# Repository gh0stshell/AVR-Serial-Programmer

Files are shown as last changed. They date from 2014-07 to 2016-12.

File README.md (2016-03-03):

AVR Serial Programmer
---------------------

This project is a small programmer for AVR microcontrollers using an RS232
serial connection. The circuit has a feature that allows the firmware to be
loaded to the target microcontroller, and the serial line to be passed through
to the target without manual intervention. A jumper setting allows for the
programmer firmware to be updated. The microcontroller used in the programmer
hardware is now the ATTiny4313. The original AT90S2313 is obsolete and the
ATTiny2313 is now too limited.

The firmware manages the programming of an expandable range of AVR
microcontrollers, FLASH, EEPROM and fuse bits, using the SPI port of the target
with the reset pin asserted. Versions of firmware are provided for the
ATTiny2313 and ATTiny4313. The former is deprecated. The latter is needed to
handle the increasing number of AVR target types.

A Linux GUI is provided. This reads the AVR fuse bits and signature bits and
adapts the GUI configuration to the detected microcontroller type. The GUI may
be used directly with a bootloader following the AVR109 command interface.

* Connect the 2-pin 5V DC power, noting the polarity is respected.
* Connect a 4-wire serial cable to the PC either directly if the PC has a serial
port, or via a serial-USB adapter. The default serial port is /dev/ttyUSB0
appropriate for the adapter. The -P command line switch allows another port to
be defined, such as /dev/ttyS0 for the PC's serial port.
* Connect the 6-pin programming cable to the target.

The GUI when invoked should show the target AVR processor type plus a number of
additional details. If the serial port is incorrect the GUI will try out a
number of baud rates and close.

Take care when changing the lock/fuse bits as this can brick the processor if
done incorrectly.

More information is provided at [Jiggerjuice](http://www.jiggerjuice.info/electronics/projects/serialprogrammer/firmware-bootloader.html).

(c) K. Sarkies 19/07/2014

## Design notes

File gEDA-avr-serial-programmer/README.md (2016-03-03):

AVR Serial Programmer PCB
-------------------------

This provides the schematic and PCB layout using gEDA and the associated pcb
tools. The final PCB is bundled with some SMPS circuits.

Tested OK.

More information is provided at [Jiggerjuice](http://www.jiggerjuice.info/electronics/projects/serialprogrammer/firmware-bootloader.html)

(c) K. Sarkies 8/11/2014

TODO
The 10 pin header will only just allow a shrouded header for a tight fit. The
board needs to be rearranged to make more room.

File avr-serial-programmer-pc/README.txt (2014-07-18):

AVR Serial Programmer GUI
=========================

Copyright 2007 Ken W. Sarkies

Target:    Linux
Author:    Ken Sarkies
Date:      28/4/2012
Licence:   GPL 2
gcc:       4.6.1
QT         4.7.4
Tested:    ATMega88, ATMega48, ATMega168, ATMega16, ATMega32, ATMEga8535,
ATTiny2313, ATTiny461, ATTiny24, ATTiny44, ATTiny84, ATTiny4313.

Depends QT4 v4.7.4, qextserialport v1.2beta1

The Serial Programmer GUI is intended for use with an AVRPROG compatible Serial
Programmer or with AVR microcontrollers that have an AVR109 compatible
bootloader installed. Normally a bootloader would need to be obtained, compiled
and programmed into the microcontroller using a suitable programming tool. Once
this has been done, the microcontroller can be contacted over an RS232 serial
line to program an application into the device. The programmer begins by opening
the PC serial port ttyUSB0 for use with a Prolific compatible USB-serial
converter. This can be changed as necessary (for example to ttyS0 if you are
using a serial port) by editing the avrserialprogmain.cpp file.

The programmer synchronizes with the device using no parity, 1 stop bit and 8
bit data. A character 0xDD is sent and the character received back from the
device is checked for either a 0xDD or a "?". The latter indicates that the
bootloader may have been found. The 0xDD character relates to the packet
protocol used in the Acquisition project. If this is received, then a packet is
sent to instruct the device to jump into the bootloader. This can be removed if
the application protocol is not needed, but that is probably not necessary.
Needless to say if the bootloader is not present the device will probably just
reset itself. If neither character is received, the baud rate is cyclically
changed through a set of standard rates for a couple of cycles before giving up.

When the program has synchronized with the device, it presents an information
window. An Intel hex file can be opened and it will be immediately read and
loaded to the application area of the FLASH memory (a bootloader is never
overwritten by this; it can only be changed through the parallel or SPI
programming method).

The default baud rate to start with is 38400 baud. If this does not match that
of the device, then the program will cycle through standard baud rates between
2400 and 57600 baud until it finds the correct one. This process can be sped up
by changing the default baud rate to match that of the programmer or bootloader.
Care must be taken with choice of baud rate as the higher rates are not
necessarily produced accurately by an MCU. In addition there are time delays,
built into the code to adapt the program to the communication response time,
that may prevent the application from working reliably. The GUI was tested
successfully with 38400 baud and 8MHz MCUs. Repetitive programming failures,
particularly in block mode programming and verification, could be due to use
with an MCU of lower frequency that takes longer to process a programming
command.

The program allows for turning off block mode, and also allows verification
without programming and vice-versa. Autoaddress currently does nothing so it is
disabled. A debug switch allows masses of information to be dumped to standard
input. Dialogue boxes for programming lock and fuse bits are provided for a
small range of devices.

The application is presented as a QT dialogue box rather than a main window. It
is done this way to allow direct integration into other applications without
recoding. When the application is closed with the Close button it automatically
instructs the bootloader to jump into the program that was just loaded.

For the AVR microcontrollers, control of program loading to the FLASH memory,
and manipulating of the fuse and lock bits for configuring certain features of
the microcontroller, can be simply done through a PC parallel port programmer
(see the cdk4avr tools howto and references). Many of the AVRs provide a small
section of FLASH memory with capabilities that allow it to modify its own FLASH
memory. This is sometimes referred to as the bootblock. It normally resides in
the top of FLASH memory and can be set, through fuse bits, to different sizes,
typically 256 bytes to 4K bytes. The microcontroller can also be configured
through a fuse bit so that after a reset, a jump directly to the bootloader
section can be forced, rather than the usual jump to address 0.

For microcontrollers that have a UART, programming can be done through a PC
serial port using the bootloader. This makes programming even simpler,
particularly for PCs and laptops that do not have a parallel port. For those
without a serial port, a commercially available USB to serial adaptor can be
used.

Some tools developed for AVR programming are presented here. Similar tools are
available in both open source and commercial versions, including bootloaders, PC
programming control applications and hardware programmers. The tools described
here were constructed to add some useful features.

    *      AVR109 Bootloader adaptation
    *      Serial Programmer GUI software
    *	   Installation
    *      Serial to SPI Programmer Hardware
    * 	   Other Open Source Programmers

AVR Bootloader

Atmel's application note AVR109 describes a bootloader that uses the UART to
communicate FLASH programming instructions. They also provide some sample code
in C that allows the programming of FLASH, EEPROM, and lock bits. Note that the
AVR109 bootloader does not support the programming of fuses which for safety
cannot be changed by the bootloader. The communication protocol used is
compatible with the AVRPROG programming software. After loading this into the
bootloader section, the device can be configured so that on reset the program
counter starts at the bootloader, and programmer software can program the FLASH
memory.

The ATMEL example bootloader program proposes the use of a port pin on the
microcontroller to signal whether to execute the bootloader program or to jump
directly to the application. This allows a user to set a jumper on the
microcontroller card that pulls the pin low when programming of the FLASH is
needed.

The adaptation of this code described here, keeps it almost unchanged in the
interests of compatibility. By disabling the port pin test and excluding the
EEPROM programming section and the AVRPROG compatibility section, the code will
fit neatly into a 1K block of the bootloader FLASH section on
ATMega48/ATMega88/ATMega168 AVRs*. Disabling the port pin test means that on
reset the microcontroller always ends up in the bootloader program (if the
appropriate fuse bit has been set), and must be explicitly sent out again with a
bootloader exit command. For the moment this is acceptable as the device will
normally operate while connected to a PC serial port. For standalone operation a
pin will need to be made available to implement the port pin test, or the
appropriate fuse bit programmed to start the device on reset at location 0. In
the latter case the application firmware will need to manage a jump to the
bootloader when firmware update is required.

Although the AVR109 code is freely available, Atmel has not released it under a
clear open source licence. As such the modified code will not be reproduced
here. Later I may write my own bootloader or find another suitable source,
however it turns out to be difficult to produce more compact C code than that
provided in Atmel's sample. There are assembler versions of the bootloader
available (e.g. that by Herbert Dingfelder) that take up less space, however
assembler code is less readable and potentially less portable than a higher
level lenguage. The changes made to the code are quite reasonable and simple
(most are corrections to perceived minor deficiencies):

   1. Modify the block read and block write functions to add a compiler
directive REMOVE_FLASH_BYTE_SUPPORT around the FLASH programming section (be
careful of if-else clauses).
   2. Modify the block read and block write functions to add a compiler
directive REMOVE_EEPROM_BYTE_SUPPORT around the EEPROM programming section (be
extra careful of if-else clauses).
   3. Move the 'E' command outside of REMOVE_AVRPROG_SUPPORT so that we can get
out of the bootloader into the application.
   4. Add a compiler directive REMOVE_PROGPIN_TEST around the the port pin check
section. This must also be added at the end of the "for" loop where the jump to
the application is made.
   5. The preprocessor.sh script can be modified to generate an all-encompassing
defines.h file covering all microcontroller types, rather than using the
suggested cut and paste system. This makes use of the availability of the MMCU
variable in avr-gcc to identify the microcontroller type.

To allow the application to execute a jump into the bootloader I used an
instruction to enable the Watchdog Timer on a very short timeout to force the
MCU to be reset, the fuses being set to send it to the bootloader section. There
seemed to be a problem either with the (old) compiler or the AVR that a long
jump was not possible. This has the advantage that it does not require the exact
address of the bootloader to be set in the code, but of course prevents the
Watchdog Timer from being used for for other purposes. I then added code to
disable the Watchdog Timer at the start of the bootloader. This turned out to be
problematical as the ATMega88 and related microcontrollers use a two step
process to prevent accidental changes to the Watchdog Timer control registers.
Therefore the code below is specific to these MCUs. A small amount of work will
be needed to adapt it to other devices. The wdt.h header file provided with
avr-libc does not support this at the time of writing.

For the bootloader, clear all reset flags in the MCUSR, and then perform a write
to WDTCSR to set the WDCE and WDE bits. This enables changes to occur in a short
timeframe. Then immediately afterwards wipe the entire register to disable the
timer.

    asm("cli");
    asm("wdr");
    MCUSR = 0;
    WDTCSR |= (1 << WDCE) | (1 << WDE);
    WDTCSR = 0;

For the application, clear all reset flags in the MCUSR, and then perform a
write to WDTCSR to set the WDCE and WDE bits to enable changes. Then immediately
afterwards perform a write to WDTCSR to set the WDE bit to enable the timer for
system resets only, with the timeout period set at its smallest value (about
15ms).

    MCUSR = 0;
    WDTCSR = (1 << WDCE) | (1 << WDE);
    WDTCSR = (1 << WDE);

Programmer GUI Application

To support the above bootloader a GUI programmer for Linux was written in QT4
and C++ (see the documentation) . This provides basic hex file load and verify,
and some fuse/lock bit programming for selected devices (do not fiddle with
these settings until you have carefully read and understood the datasheets). The
programmer opens a serial port (which may need to be changed to match the target
system) and synchronizes with the device using no parity, 1 stop bit and 8 bit
data. A character 0xDD is sent and the character received back from the device
is checked for either a 0xDD or a "?". The latter indicates that the bootloader
may have been found. The 0xDD character relates to the packet protocol used in
the Acquisition project. If this is received, then a packet is sent to instruct
the device to jump to the bootloader. This can be removed if the packet protocol
is not needed, but that is not really necessary as the bootloader will just
reject anything unknown. If the bootloader is not present the device will
probably just reset itself. If neither character is received, the baud rate is
cyclically changed through a set of standard rates for a couple of cycles.

When the program has synchronized with the device, it gathers a swag of
information and presents the above window. Note that unlike avrdude it assumes
that a valid and working AVR device is connected. An Intel hex file can be
opened and will be immediately read and loaded to the application area of the
device FLASH.

The default baud rate to start with is 38400 baud. If this does not match that
of the device, then the program will cycle through standard baud rates between
2400 and 57600 baud until it finds the correct one. This process can be sped up
by changing the default baud rate to match that of the bootloader.

The program allows for turning off block mode, and also allows verification
without programming and vice-versa. Autoaddress currently does nothing so it is
disabled. There is a chip erase feature provided: normally the E button is
invisible until the checkbox has been selected to minimize accidental erasures.
An erase may be necessary if the lock bits have been set incorrectly. This
requires an external programmer. A bootloader will not reset the lock bits.

The GUI program relies on inserting delays into the serial communications to
adapt the speed of the PC to the bootloader or serial programmer. Also when
waiting for a response from the programmer, the program will timeout if this
takes too long. If problems are experienced while programming or verifying, it
may be that these delays need to be increased. This is particularly the case if
the clock speed used with the MCU is low. The GUI program was tested with 8MHz
MCU clock frequencies and 38400 baud communications.

Additional sections have been added to enable fuse and lock bits to be read and
changed for a limited number of devices. The program uses the device signature
bytes to identify the device uniquely, and the appropriate window is invoked.
This has only been partly tested so use it at your own risk.

The program also supports a limited command line feature to allow a much faster
non-GUI usage during intensive AVR development and testing work. The command
line options are:

-n	no GUI
-b	initial baudrate (baud)
-P	port (eg /dev/ttyUSB0)
-w	write hex file to device
-v	validate
-d	debug mode
-x	pass through serial comms on exit

Thus the command:

$ ./avrserialprog -n -b 19200 -P /dev/ttyUSB0 -w ../test/test.hex -v -d -x

will use the non-GUI mode, an initial baudrate of 19200 baud (only the standard
rates from 2400 to 115200 are supported), the given serial port (the one shown
uses a USB to serial adapter), to write the file shown with verification, to
give pages of useless debug information, and to pass through serial
communications at the end (so that the PC can communicate without removing the
programmer). The -x parameter is only useful if the programmer described below
is attached. In the GUI mode, the command line baud rate and port parameters can
be used to set those values in the program, but the other parameters will be
ignored.

Changes:

1/11/2010 Added a checkbox to the GUI to allow the program to pass through the
serial communications to the target device.

13/11/2010 Updated the AVR code to add more devices and to compile for the
ATTiny2313. The MCU needs to be changed in the Makefile and also at the top of
the .c file. The code now incorporates the serial link functions and is self
contained.

13/11/2010 The old AT90S2313 has been added but so far does not program
correctly. It doesn't support FLASH page programming and would require
additional code in the AVR for special handling. As code memory is too limited
it has been omitted from the AVR code (although it remains in the GUI). The
larger device ATTiny4313 would be needed to support the additional code.

14/11/2010 The AVR code now enables the SPI output ports only when programming
mode is entered, and reverts them to inputs as soon as programming mode quits.
This enables the sharing of the SPI ports for small devices when using
in-circuit programming.

13/10/2011 Some refactoring to move GUI specific code away from programmer
operations code. Addition of features to provide command line operation.

28/04/2012 Addition of an include for QFile in the header file (which seems
to have not been needed before). version 1.2Beta of qextserialport fails.
Nothing returned from availableBytes().

K. Sarkies 13/10/2011

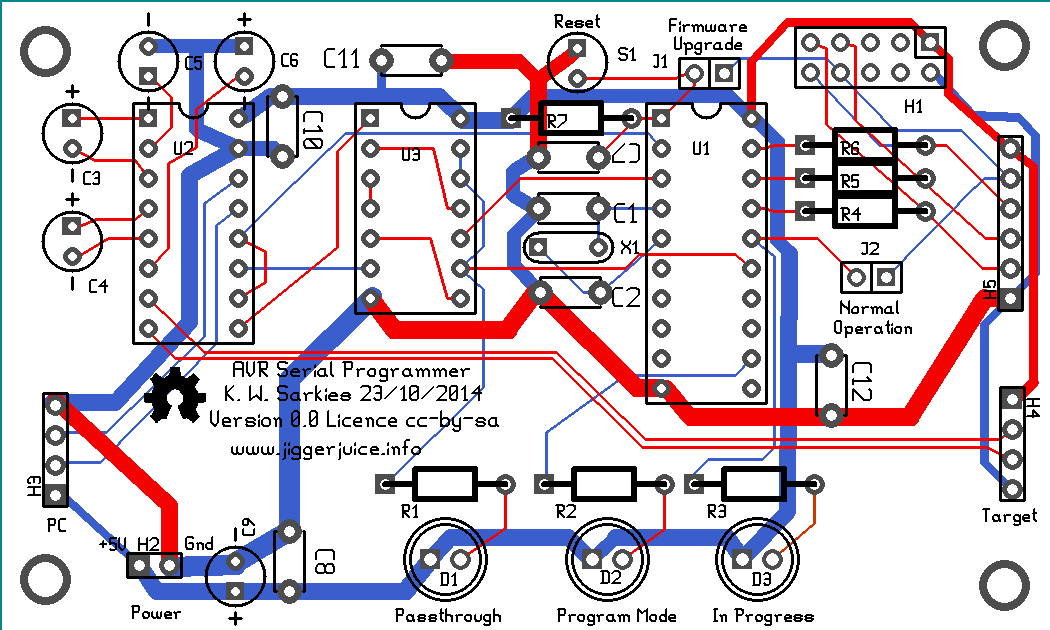
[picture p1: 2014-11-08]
gEDA-avr-serial-programmer/avr-serial-programmer-pcb.png

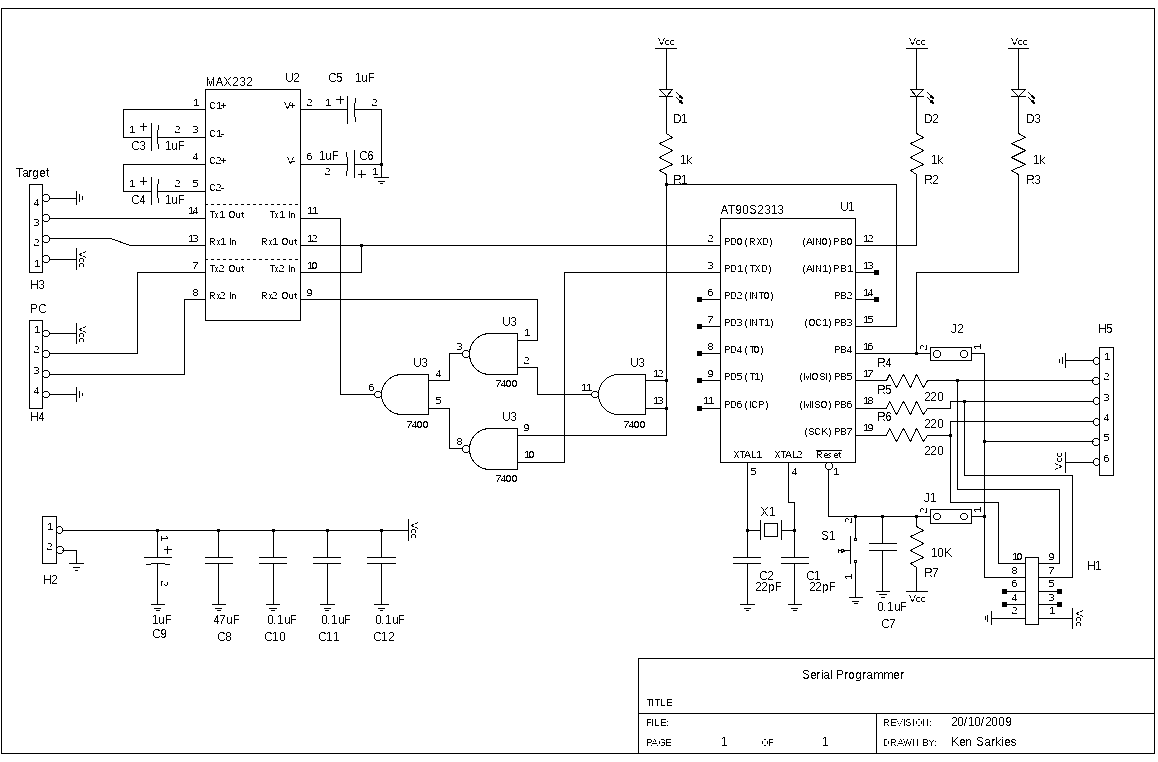
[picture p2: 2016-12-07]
gEDA-avr-serial-programmer/avr-serial-programmer.png

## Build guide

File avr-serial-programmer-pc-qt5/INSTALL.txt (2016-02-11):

Basic Installation
==================

To use this, unpack into a directory which by default will be
serial-programmer-pc.

Make sure that QT5, qt4-designer, qmake-qt5 are installed and also under Ubuntu
install libqt5serialport5-dev and libudev-dev.

Return to the serial-programmer-pc directory. The default serial port used is
/dev/ttyUSB0 This can be changed in the command line. Execute:

$ make clean
$ qmake
$ make

This will build the application. Copy the binary to a suitable place and invoke
with:

$ avrserialprog

A range of command line parameters are available for GUI-less usage
(see the README).

K. Sarkies
12/2/2016

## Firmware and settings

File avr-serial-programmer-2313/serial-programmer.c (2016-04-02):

/**
@mainpage Atmel Serial Programmer for AVR 2313 version
@version 0.1
@author Ken Sarkies (www.jiggerjuice.net)
@date 14 November 2010

@brief Code for the embedded portion of the Battery Charger Project,
for an 8MHz Atmel MCU AT90S2313.

@details This is the AVR code for the stand-alone serial programmer that interfaces to
the PC via a serial (USB) link and to the target via the SPI interface.

The board is designed to receive serial commands that are compatible with the AVRPROG
command set, and to activate the SPI interface to program a target AVR microcontroller.
The board uses the AT90S2313 (probably obsolete) AVR microcontroller (which can be
replaced by the ATTiny2313).

The SPI port is used along with an additional output pin used to hold the target in a reset
state. When programming has been completed, the board switches the serial communications to
pass through to the target. This switches the incoming serial communications from the target
through to the PC. The outgoing communications from the PC are simply copied to the target.

Refer to the Project documents for more details.

The main differences between targets are:
1. The availability of a busy status. If not available, fixed delays need to be added
   where memory accesses are made, or rereading of the memory location.
2. The use of paged or individual FLASH memory programming. EEPROM can always be accessed
   individually, but some devices allow paged writes.
3. The size of the memory pages. The AT90S2313 and ATTiny2313 are limited to 32 word page
   support.
4. The need to access Fuse, High Fuse and Extended Fuse bits.
5. While all have programmable lock bits, not all can be read.

Currently all the above are supported and no distinction is made.

@note
Compiler: avr-gcc (GCC) 3.4.5 (CDK4AVR 3.0 3.4.5-20060708)
@note
Target: AT90S2313, ATTiny2313 at 8.0MHz
@note
Tested: AT90S2313, ATTiny2313 at 8.0MHz
@note
Uses: serial.c, defines.h, flash.h written by R Aapeland (?)
@todo Where a fuse/lock capability is tested and the command within the if
statement contains a recchar() call, move the latter out of the if to allow the
protocol to complete correctly even if the capability is not supported.
*/
/****************************************************************************
 *   Copyright (C) 2007 by Ken Sarkies ksarkies@internode.on.net            *
 *                                                                          *
 *   This file is part of serial-programmer                                 *
 *                                                                          *
 *   serial-programmer is free software; you can redistribute it and/or     *
 *   modify it under the terms of the GNU General Public License as         *
 *   published by the Free Software Foundation; either version 2 of the     *
 *   License, or (at your option) any later version.                        *
 *                                                                          *
 *   serial-programmer is distributed in the hope that it will be useful,   *
 *   but WITHOUT ANY WARRANTY; without even the implied warranty of         *
 *   MERCHANTABILITY or FITNESS FOR A PARTICULAR PURPOSE.  See the          *
 *   GNU General Public License for more details.                           *
 *                                                                          *
 *   You should have received a copy of the GNU General Public License      *
 *   along with serial-programmer. If not, write to the Free Software       *
 *   Foundation, Inc.,                                                      *
 *   51 Franklin St, Fifth Floor, Boston, MA  02110-1301  USA.              *
 ***************************************************************************/

#include <inttypes.h>
#include <avr/eeprom.h>
#include <avr/sfr_defs.h>
#include <avr/io.h>
#include <avr/wdt.h>

// Definitions of microcontroller registers and other characteristics
#define	_ATtiny2313
//#define	_AT90S2313
#ifdef	__ICCAVR__
#include "iotn2313.h"
#elif	__GNUC__
#include <avr/io.h>
#endif

#define TRUE 1
#define FALSE 0
/* Convenience macros (we don't use them all) */
#define  _BV(bit) (1 << (bit))
#define  inb(sfr) _SFR_BYTE(sfr)
#define  inw(sfr) _SFR_WORD(sfr)
#define  outb(sfr, val) (_SFR_BYTE(sfr) = (val))
#define  outw(sfr, val) (_SFR_WORD(sfr) = (val))
#define  cbi(sfr, bit) (_SFR_BYTE(sfr) &= ~_BV(bit))
#define  sbi(sfr, bit) (_SFR_BYTE(sfr) |= _BV(bit))
#define  high(x) ((uint8_t) (x >> 8) & 0xFF)
#define  low(x) ((uint8_t) (x & 0xFF))

#include "serial-programmer.h"
#include <util/delay.h>

/***************************************************************************************/
/* Functions to send/receive */

/* This defines our baudrate 25=19200, 12=38400, 8=57600 */
#define BRREG_VALUE             12

/* definitions for UART control */
#ifdef _ATtiny2313
#define	UART_STATUS UCSRA
#endif
#ifdef _AT90S2313
#define	UART_STATUS USR
#endif

/***************************************************************************************/
void initbootuart(void)
{
#ifdef _ATtiny2313
    UBRRL = BRREG_VALUE;
    UBRRH = 0;
    UCSRA = 0;
    UCSRB = (1 << RXEN) | (1 << TXEN);  // enable receive and transmit 
    UCSRC = 6;                          // Set to 8-bit mode
#endif
#ifdef _AT90S2313
    UBRR = BRREG_VALUE;
    USR = (1 << RXEN) | (1 << TXEN);  // enable receive and transmit 
#endif
}

/***************************************************************************************/
void sendchar(unsigned char c)
{
    UDR = c;                                // Load data to Tx buffer
    while (!(UART_STATUS & (1 << TXC)));    // wait until sent
    UART_STATUS |= (1 << TXC);              // clear TXCflag
}

/***************************************************************************************/
unsigned char recchar(void)
{
  while(!(UART_STATUS & (1 << RXC)));       // wait for data
  return UDR;
}

/***************************************************************************************/
/** @brief Array of parts and properties

This lists all the target devices supported by the programmer.

The first signature byte is assumed to be always E1. If not, then we abort programming.
Flash and EEPROM page sizes zero means that page writes are not supported.
Lock and Fuse support is given by a bitwise quantity.
0 = Lock Read
1 = Fuse Read
2 = High Fuse Read
3 = Extended Fuse Read
4 = Lock Write
5 = Fuse Write
6 = High Fuse Write
7 = Extended Fuse Write
*/

/* Define the parts to be stored into EEPROM.
We can't do the AT90S2313 as it runs us out of space.
FPage is the FLASH  pagesize in words
EPage is the EEPROM pagesize in bytes
*/
#define NUMPARTS 13
uint8_t part[NUMPARTS][6] = {
/* Sig 2, Sig 3, FPage, EPage, Busy, Lock/Fuse */
//{   0x91,  0x01,    0,    0,   FALSE,  0x10     },  // AT90S2313
//{   0x91,  0x0B,   16,    4,   TRUE,   0xFF     },  // ATTiny24
{   0x91,  0x09,   16,    0,   FALSE,  0x77     },  // ATTiny26
{   0x91,  0x0A,   16,    4,   TRUE,   0xFF     },  // ATTiny2313
{   0x91,  0x0C,   16,    4,   TRUE,   0xFF     },  // ATTiny261
{   0x92,  0x07,   32,    4,   TRUE,   0xFF     },  // ATTiny44
{   0x92,  0x0D,   32,    4,   TRUE,   0xFF     },  // ATTiny4313
{   0x92,  0x05,   32,    4,   TRUE,   0xFF     },  // ATMega48
{   0x92,  0x08,   32,    4,   TRUE,   0xFF     },  // ATTiny461
//{   0x93,  0x0C,   32,    4,   TRUE,   0xFF     },  // ATTiny84
{   0x93,  0x08,   32,    0,   FALSE,  0x77     },  // ATMega8535
{   0x93,  0x0A,   32,    4,   TRUE,   0xFF     },  // ATMega88
{   0x93,  0x0D,   32,    4,   TRUE,   0xFF     },  // ATTiny861
{   0x94,  0x03,   64,    4,   TRUE,   0x77     },  // ATMega16
{   0x94,  0x06,   64,    4,   TRUE,   0xFF     },  // ATMega168
{   0x95,  0x02,   64,    0,   FALSE,  0x77     }   // ATMega32
};
/***************************************************************************************/

uint16_t address;                   // Address to program
uint8_t command;                    // received instruction character
uint16_t tempInt;
uint8_t lsbAddress;
uint8_t msbAddress;
uint8_t buffer[4];                  // Buffer to store response from target
uint8_t fPageSize;
uint8_t ePageSize;
uint8_t canCheckBusy;
uint8_t lfCapability;
uint8_t received;

int main(void)
{

/*  Initialise hardware timers and ports. All start off as inputs */
/*  PD0 is RxD
    PD1 is TxD */
/** PORTB is set as outputs on bits 0,3,4 to set controls.
    The SPI output ports SCK and MOSI stay as inputs until ready to program.
    Set the Ports PB0-2 as outputs and set high to turn off all LEDs
    PB0 = programming mode LED
    PB3 = programming completed LED (and serial comms switch over)
    PB4 = programming active LED (and reset out)
    PB5 = MOSI
    PB6 = MISO
    PB7 = SCK */

    sbi(ACSR,7);                                        // Turn off Analogue Comparator
    initbootuart();           	                        // Initialize UART.
    uint8_t sigByte1=0;                                 // Target Definition defaults
    uint8_t sigByte2=0;
    uint8_t sigByte3=0;
    uint8_t fuseBits=0;
    uint8_t highFuseBits=0;
    uint8_t extendedFuseBits=0;
    uint8_t lockBits=0;

/*---------------------------------------------------------------------------*/
/* Main loop. We exit this only with an "E" command. */
    {
        for(;;)
        {
            command=recchar();                          // Loop and wait for command character.

/** 'a' Check autoincrement status.
This allows a block of data to be uploaded to consecutive addresses without
specifying the address each time */
            if (command=='a')
            {
                sendchar('Y');                          // Yes, we will autoincrement.
            }

/** 'A' Set address.
This is stored and incremented for each upload/download.
NOTE: Flash addresses are given as word addresses, not byte addresses. */
            else if (command=='A')                       // Set address
            {
                address = (recchar()<<8);               // Set address high byte first.
                address |= recchar();                   // Then low byte.
                sendchar('\r');                         // Send OK back.
            }

/** 'b' Check block load support. This returns the allowed block size.
We will not buffer anything so we will use the FLASH page size to limit
the programmer's blocks to those that will fit the target's page. This then avoids
the long delay when the page is committed, that may cause incoming data to be lost.
This should not be called before the P command is executed, and the target device
characteristics obtained. The fPageSize characteristic should be non zero.*/
           else if (command=='b')
            {
                uint16_t blockLength = ((uint16_t)fPageSize<<1);
                if (fPageSize > 0) sendchar('Y');       // Report block load supported.
                else sendchar('N');
                sendchar(high(blockLength));            // MSB first.
                sendchar(low(blockLength));             // Report FLASH pagesize (bytes).
            }

/** 'p' Get programmer type. This returns just 'S' for serial. */
            else if (command=='p')
            {
                sendchar('S');                          // Answer 'SERIAL'.
            }

/** 'S' Return programmer identifier. Always 7 digits. We call it AVRSPRG */
            else if (command=='S')
            {
                sendchar('A');
                sendchar('V');                          // ID always 7 characters.
                sendchar('R');
                sendchar('S');
                sendchar('P');
                sendchar('R');
                sendchar('G');
            }

/** 'V' Return software version. */
            else if (command=='V')
            {
                sendchar('0');
                sendchar('0');
            }

/** 't' Return supported device codes. This returns a list of devices that can be programmed.
This is only used by AVRPROG so we will not use it - we work with signature bytes instead. */
            else if(command=='t')
            {
                sendchar( 0 );                          // Send list terminator.
            }

/** 'x' Set LED. */
            else if ((command=='x') || (command=='y') || (command=='T'))
            {
//                if (command=='x') sbi(PORTB,LED);
//                else if (command=='y') cbi(PORTB,LED);
                recchar();                              // Discard sent value
                sendchar('\r');                         // Send OK back.
            }

/** 'P' Enter programming mode.
This starts the programming of the device. Pulse the reset line high while SCK is low.
Send the command and ensure that the echoed second byte is correct, otherwise redo.
With this we get the device signature and search the table for its characteristics.
A timeout is provided in case the device doesn't respond. This will allow fall through
to an ultimate error response.
The reset line is held low until programming mode is exited. */
            else if (command=='P')
            {
                outb(DDRB,(inb(DDRB) | 0xB9));          // Setup SPI output ports
                outb(PORTB,(inb(PORTB) | 0xB9));        // SCK and MOSI high, and LEDs off
                uint8_t retry = 10;
                uint8_t result = 0;
                while ((result != 0x53) && (retry-- > 0))
                {
                    cbi(PORTB,SCK);                     // Set serial clock low
                    sbi(PORTB,RESET);                   // Pulse reset line off
                    _delay_us(100);                     // Delay to let CPU know that programming will occur
                    cbi(PORTB,RESET);                   // Pulse reset line on
                    _delay_us(25000);                   // 25ms delay
                    writeCommand(0xAC,0x53,0x00,0x00);  // "Start programming" command
                    result=buffer[2];
                }
/** Once we are in programming mode, grab the signature bytes and extract all information
about the target device such as its memory sizes, page sizes and capabilities. */
                writeCommand(0x30,0x00,0x00,0x00);
                sigByte1 = buffer[3];
                writeCommand(0x30,0x00,0x01,0x00);
                sigByte2 = buffer[3];
                writeCommand(0x30,0x00,0x02,0x00);      // Signature Bytes
                sigByte3 = buffer[3];
/* Check for device support. If the first signature byte is not 1E, then the device is
either not an Atmel device, is locked, or is not responding.*/
                uint8_t found=FALSE;                    // Indicates if the target device is supported
                uint8_t partNo = 0;
                if (sigByte1 == 0x1E)
                {
                    while ((partNo < NUMPARTS) && (! found))
                    {
                        found = ((part[partNo][0] == sigByte2) && (part[partNo][1] == sigByte3));
                        partNo++;
                    }
                }
                if (found)
                {
                    partNo--;
                    sendchar('\r');
                    fPageSize = part[partNo][2];
                    ePageSize = part[partNo][3];
                    canCheckBusy = part[partNo][4];
                    lfCapability = part[partNo][5];
                    buffer[3] = 0;                      // In case we cannot read these
                    if (lfCapability & 0x08) writeCommand(0x50,0x08,0x00,0x00);  // Read Extended Fuse Bits
                    extendedFuseBits = buffer[3];
                    if (lfCapability & 0x04) writeCommand(0x58,0x08,0x00,0x00);  // Read High Fuse Bits
                    highFuseBits = buffer[3];
                    if (lfCapability & 0x02) writeCommand(0x50,0x00,0x00,0x00);  // Read Fuse Bits
                    fuseBits = buffer[3];
                    if (lfCapability & 0x01) writeCommand(0x58,0x00,0x00,0x00);  // Read Lock Bits
                    lockBits = buffer[3];
                }
                else                                    // Not found?
                {
                    sbi(PORTB,RESET);                   // Lift reset line
                    sendchar('?');                      // Device cannot be programmed
                    outb(DDRB,(inb(DDRB) & ~0xA0));     // Set SPI ports to inputs
                }
            }

/** 'L' Leave programming mode. */
            else if(command=='L')
            {
                sbi(PORTB,RESET);                       // Turn reset line off
                sendchar('\r');                         // Answer OK.
                outb(DDRB,(inb(DDRB) & ~0xA0));         // Set SPI ports to inputs
            }

/** 'e' Chip erase.
This requires several ms. Ensure that the command has finished before acknowledging. */
            else if (command=='e')
            {
                writeCommand(0xAC,0x80,0x00,0x00);      // Erase command
                pollDelay(FALSE);
                sendchar('\r');                         // Send OK back.
            }

/** 'R' Read program memory */
            else if (command=='R')
            {
/** Send high byte, then low byte of flash word.
Send each byte from the address specified (note address variable is modified).*/
                lsbAddress = low(address);
                msbAddress = high(address);
                writeCommand(0x28,msbAddress,lsbAddress,0x00);  // Read high byte
                sendchar(buffer[3]);
                writeCommand(0x20,msbAddress,lsbAddress,0x00);  // Read low byte
                sendchar(buffer[3]);
                address++;                              // Auto-advance to next Flash word.
            }

/** 'c' Write to program memory page buffer, low byte.
NOTE: Always use this command before sending the high byte. It is written to the
page but the address is not incremented.*/
            else if (command=='c')
            {
                received = recchar();
                writeCommand(0x40,0x00,address & 0x7F,received);    // Low byte
                sendchar('\r');                         // Send OK back.
            }

/** 'C' Write to program memory page buffer, high byte.
This will cause the word to be written to the page and the address incremented. It is
the responsibility of the user to issue a page write command.*/
            else if (command=='C')
            {
                received = recchar();
                writeCommand(0x48,0x00,address & 0x7F,received);    // High Byte
                address++;                              // Auto-advance to next Flash word.
                sendchar('\r');                         // Send OK back.
            }

/** 'm' Issue Page Write. This writes the target device page buffer to the Flash.
The address is that of the page, with the lower bits masked out.
This requires several ms. Ensure that the command has finished before acknowledging.
We could check for end of memory here but that would require storing the Flash capacity
for each device. The calling program will know in any case if it has overstepped.*/
            else if (command== 'm')
            {
                writeCommand(0x4C,(address>>8) & 0x7F,address & 0xE0,0x00);  // Write Page
                pollDelay(TRUE);                        // Short delay
                sendchar('\r');                         // Send OK back.
            }
/** 'D' Write EEPROM memory
This writes the byte directly to the EEPROM at the specified address.
This requires several ms. Ensure that the command has finished before acknowledging.*/
            else if (command == 'D')
            {
                lsbAddress = low(address);
                msbAddress = high(address);
                writeCommand(0xC0,msbAddress,lsbAddress,recchar());     // EEPROM byte
                address++;                              // Auto-advance to next EEPROM byte.
                pollDelay(FALSE);                       // Long delay
                sendchar('\r');                         // Send OK back.
            }

/** 'd' Read EEPROM memory */
            else if (command == 'd')
            {
                lsbAddress = low(address);
                msbAddress = high(address);
                writeCommand(0xA0,msbAddress,lsbAddress, 0x00);
                sendchar(buffer[3]);
                address++;                              // Auto-advance to next EEPROM byte.
            }

/** 'B' Start block load.
 The address must have already been set otherwise it will be undefined. */
            else if (command=='B')
            {
                tempInt = (recchar()<<8);               // Get block size high byte first.
                tempInt |= recchar();                   // Low Byte.
                sendchar(BlockLoad(tempInt,recchar(),&address));  // Block load.
            }

/** 'g' Start block read.
 The address must have already been set otherwise it will be undefined.*/
            else if (command=='g')
            {
                tempInt = (recchar()<<8);               // Get block size high byte first.
                tempInt |= recchar();                   // Low Byte.
                command = recchar();                    // Get memory type
                BlockRead(tempInt,command,&address);    // Block read
            }
/** 'r' Read lock bits. */
            else if (command=='r')
            {
                sendchar(lockBits);
            }

/** 'l' Write lockbits. */
            else if (command=='l')
            {
                if (lfCapability & 0x10) writeCommand(0xAC,0xE0,0x00,recchar());
                sendchar('\r');                         // Send OK back.
            }

/** 'F' Read fuse bits. */
            else if (command=='F')
            {
                sendchar(fuseBits);
            }
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

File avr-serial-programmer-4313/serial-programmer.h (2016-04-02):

/*          Serial Programmer for AVR 4313 version
      Ken Sarkies ksarkies@internode.on.net
            (www.jiggerjuice.net)

File              : serial-programmer.h
Compiler          : AVR-GCC/avr-libc(>= 1.2.5)
Revision          : $Revision: 0.1 $
Updated by        : $ author K. Sarkies 14/11/2010 $

Target platform   : AT90S2313 or ATTiny2313
*/

/****************************************************************************
 *   Copyright (C) 2007 by Ken Sarkies ksarkies@internode.on.net            *
 *                                                                          *
 *   This file is part of serial-programmer                                 *
 *                                                                          *
 *   serial-programmer is free software; you can redistribute it and/or     *
 *   modify it under the terms of the GNU General Public License as         *
 *   published by the Free Software Foundation; either version 2 of the     *
 *   License, or (at your option) any later version.                        *
 *                                                                          *
 *   serial-programmer is distributed in the hope that it will be useful,   *
 *   but WITHOUT ANY WARRANTY; without even the implied warranty of         *
 *   MERCHANTABILITY or FITNESS FOR A PARTICULAR PURPOSE.  See the          *
 *   GNU General Public License for more details.                           *
 *                                                                          *
 *   You should have received a copy of the GNU General Public License      *
 *   along with serial-programmer. If not, write to the Free Software       *
 *   Foundation, Inc.,                                                      *
 *   51 Franklin St, Fifth Floor, Boston, MA  02110-1301  USA.              *
 ***************************************************************************/

/* baud rate register value calculation */
#ifndef F_CPU
#define F_CPU    8000000
#endif
#define BAUD_RATE   19200

/* Time for SPI to settle before next operation. Larger means slower loads. */
#define SPI_DELAY   2

/* FLASH Pagesize in words */
#define FPAGESIZE   32
/* EEPROM Pagesize in words */
#define EPAGESIZE   4

/* define pin for entering self programming mode */
#define SCK         PB7		// SCK   pin of the target (output)
#define MISO        PB6		// MISO  pin of the target (input)
#define MOSI        PB5		// MOSI  pin of the target (output)
#define RESET       PB4		// RESET pin of the target (output)
#define PASSTHROUGH PB3     // Pull low to allow serial port passthrough to target
#define LEDPROG     PB1		// dual color LED output, anode green  (output)
#define LED         PB0		// LED output, active low, dual color LED cathode green (output)

unsigned char BlockLoad(const unsigned int size,
                        const unsigned char mem,
                        uint16_t *address);
void BlockRead(const unsigned int size,
                        const unsigned char mem,
                        uint16_t *address);
uint8_t writeByte(const uint8_t datum);
void writeCommand(uint8_t, uint8_t, uint8_t, uint8_t);
void pollDelay(const uint8_t shortDelay);

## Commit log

2014-10-23 Update schematic with filter caps Update PCB to final version Generate gerbers
    [avr-serial-programmer.sch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]
2014-10-24 Minor changes to PCB and schematic.
    [avr-serial-programmer.sch]
2014-10-24 Combine PCBs for programmer and some SMPS for manufacture.
    [avr-serial-programmer-plus-smps.back.gbl, avr-serial-programmer-plus-smps.backmask.gbs, avr-serial-programmer-plus-smps.backsilk.gbo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]
2014-10-25 Update PCB to add mounting holes and cutouts for composite board.
    [avr-serial-programmer-plus-smps.back.gbl, avr-serial-programmer-plus-smps.backmask.gbs, avr-serial-programmer-plus-smps.backsilk.gbo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]
2014-10-26 Add gafrc, update schematics and PCB. Rebuild composite PCB with three different SMPS circuits.
    [avr-serial-programmer-plus-smps.back.gbl, avr-serial-programmer-plus-smps.backmask.gbs, avr-serial-programmer-plus-smps.backsilk.gbo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]
2014-10-26 Add image of PCB
2014-10-31 Remove SMPS from PCB and submit to manufacturer
    [avr-serial-programmer-plus-smps.back.gbl, avr-serial-programmer-plus-smps.backmask.gbs, avr-serial-programmer-plus-smps.front.gtl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]
2014-11-08 Modify silkscreen to interchange target-pc labels.
2016-04-02 Change SPI delay time. Update copyrights on firmware files.
2016-12-07 Fix bug in baudrate parameter passed via command line to add 1200 baud and so match the values set by the program.
    Some doc updates.
    [avr-serial-programmer.sch]
